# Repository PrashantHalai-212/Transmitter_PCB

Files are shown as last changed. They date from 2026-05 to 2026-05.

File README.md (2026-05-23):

# Transmitter_PCB

A Batman-inspired Batarang-shaped wireless transmitter board featuring an ATmega328P microcontroller, NRF24L01 module, and onboard CH340G USB programmer. Essentially an Arduino with integrated wireless capability and custom PCB design shaped like Batman's iconic throwing weapon.

## PCB Design

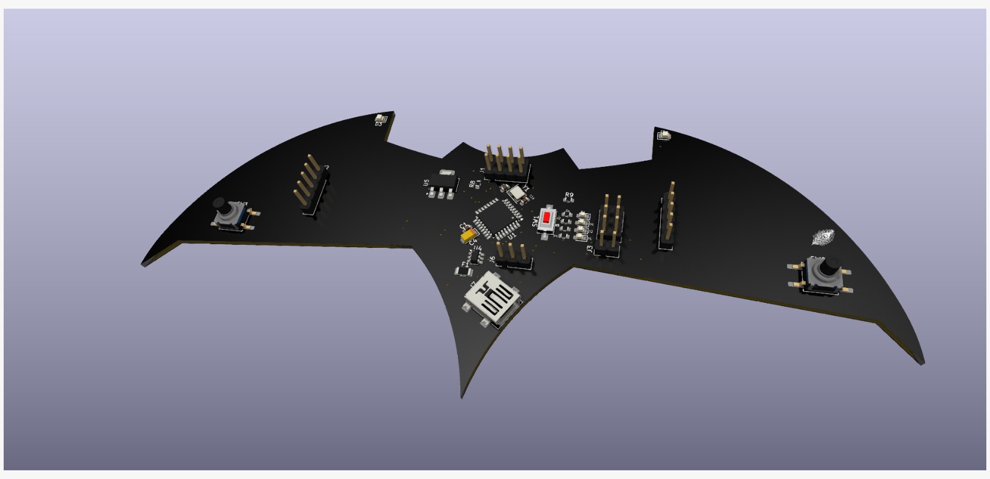
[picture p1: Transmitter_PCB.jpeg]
Batarang PCB Render


## Features

- **ATmega328P Microcontroller** - Same as Arduino
- **NRF24L01 Wireless Module** - 2.4GHz RF Communication
- **CH340G USB Programmer** - Direct programming without external programmer
- **Batarang Shape** - Batman-inspired custom PCB design
- **Full Arduino Compatibility** - Use standard Arduino sketches
- **All Supporting Components** - Crystal oscillator, capacitors, USB connector

## Files

- `Transmitter_PCB.kicad_sch` - Schematic design
- `Transmitter_PCB.kicad_pcb` - PCB layout
- `Transmitter_PCB.kicad_pro` - Project file

## Requirements

- KiCad 6.0 or later
- Arduino IDE (for programming)

## License

MIT

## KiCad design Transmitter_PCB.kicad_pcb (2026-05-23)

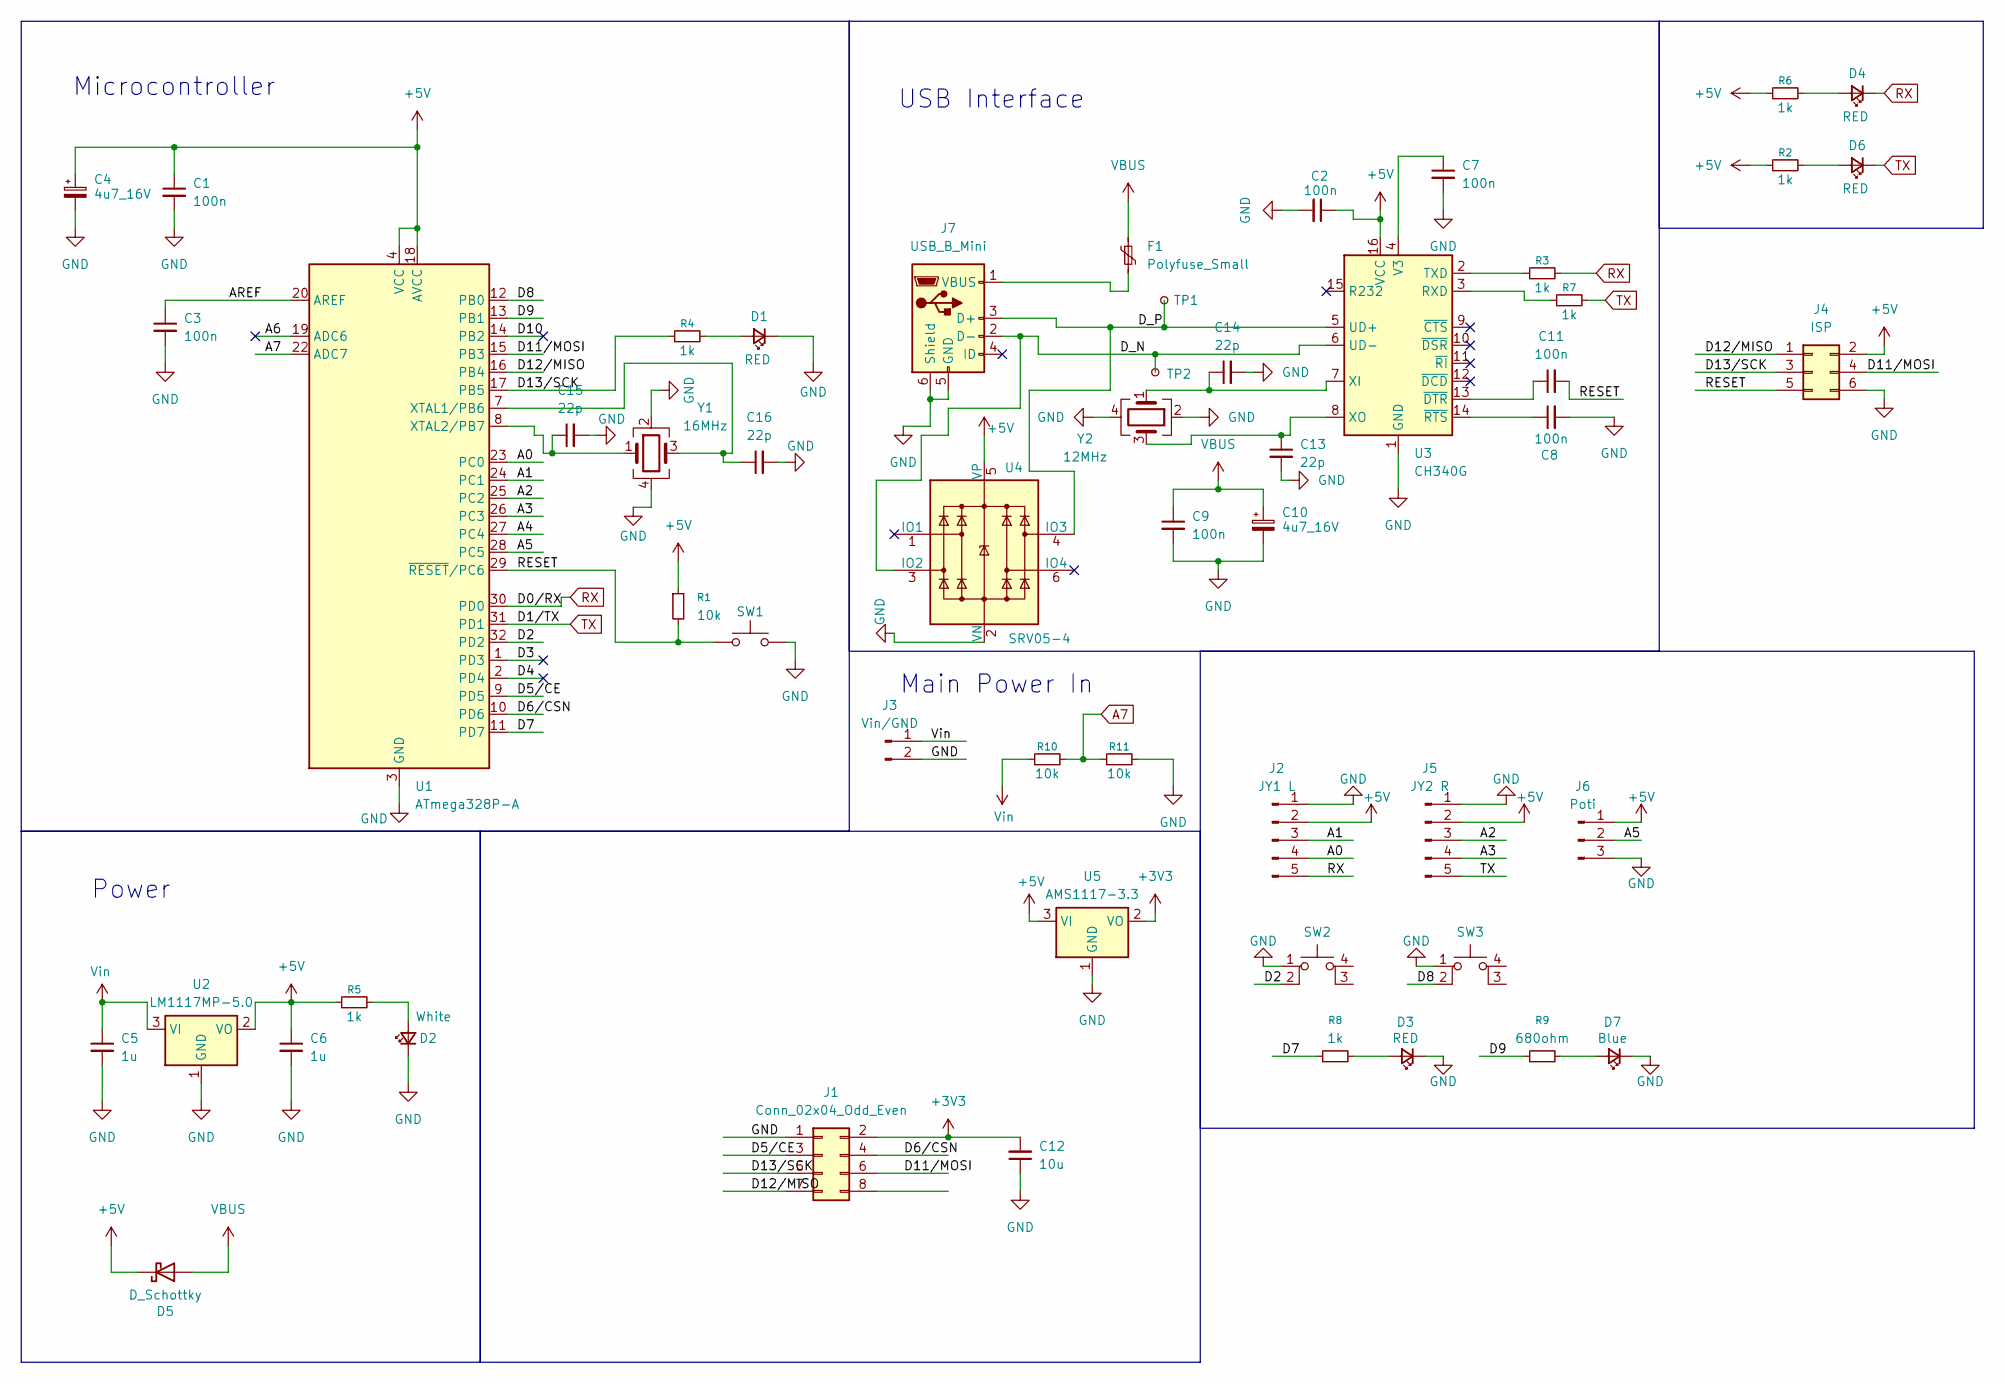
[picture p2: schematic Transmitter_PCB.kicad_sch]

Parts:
C1, C2, C3, C7, C8, C9, C11: 100n; C_0603_1608Metric
C4, C10: 4u7_16V; CP_EIA-3216-10_Kemet-I
C5, C6: 1u; C_0603_1608Metric
C12: 10u; C_0603_1608Metric
C13, C14, C15, C16: 22p; C_0603_1608Metric
D1, D4, D6: RED; LED_0603_1608Metric_Pad1.05x0.95mm_HandSolder
D2: White; LED_0603_1608Metric_Pad1.05x0.95mm_HandSolder
D3: RED; LED_0805_2012Metric
D5: D_Schottky; D_SOD-123
D7: Blue; LED_0805_2012Metric
F1: Polyfuse_Small; Fuse_1206_3216Metric
J1: Conn_02x04_Odd_Even; PinHeader_2x04_P2.54mm_Vertical
J2: JY1 L; PinHeader_1x05_P2.54mm_Vertical
J3: Vin/GND; PinHeader_1x02_P2.54mm_Vertical
J4: ISP; PinHeader_2x03_P2.54mm_Vertical
J5: JY2 R; PinHeader_1x05_P2.54mm_Vertical
J6: Poti; PinHeader_1x03_P2.54mm_Vertical
J7: USB_B_Mini; USB_Mini-B_Lumberg_2486_01_Horizontal
R1, R10, R11: 10k; R_0603_1608Metric
R2, R3, R4, R5, R6, R7, R8: 1k; R_0603_1608Metric
R9: 680ohm; R_0603_1608Metric
SW1: SW_Push; SW_SPST_CK_RS282G05A3
SW2, SW3: SW_Push_1P1T_NO_CK_KSC6xxG
TP1, TP2: TestPoint_Small; TestPoint_Pad_D1.0mm
U1: ATmega328P-A; TQFP-32_7x7mm_P0.8mm
U2: LM1117MP-5.0; SOT-223-3_TabPin2
U3: CH340G; SOIC-16_3.9x9.9mm_P1.27mm
U4: SRV05-4; SOT-23-6
U5: AMS1117-3.3; SOT-223-3_TabPin2
Y1: 16MHz; Crystal_SMD_3225-4Pin_3.2x2.5mm
Y2: 12MHz; Crystal_SMD_3225-4Pin_3.2x2.5mm

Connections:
+3V3: C12.2, J1.2, U5.2 (VO)
+5V: C1.1, C2.1, C4.1, C6.1, D5.1 (K), J2.2, J4.2, J5.2, J6.1, R1.1, R2.1, R5.1, R6.1, U1.4 (VCC), U1.6 (VCC), U1.18 (AVCC), U2.2 (VO), U3.16 (VCC), U4.5 (VP), U5.3 (VI)
/A0: J2.4, U1.23 (PC0)
/A1: J2.3, U1.24 (PC1)
/A2: J5.3, U1.25 (PC2)
/A3: J5.4, U1.26 (PC3)
/A4: U1.27 (PC4)
/A5: J6.2, U1.28 (PC5)
/A6: U1.19 (ADC6)
/AREF: C3.1, U1.20 (AREF)
/D2: SW2.2, U1.32 (PD2)
/D3: U1.1 (PD3)
/D4: U1.2 (PD4)
/D5/CE: J1.3, U1.9 (PD5)
/D6/CSN: J1.4, U1.10 (PD6)
/D7: R8.1, U1.11 (PD7)
/D8: SW3.2, U1.12 (PB0)
/D9: R9.1, U1.13 (PB1)
/D10: U1.14 (PB2)
/D11/MOSI: J1.6, J4.4, U1.15 (PB3)
/D12/MISO: J1.7, J4.1, U1.16 (PB4)
/D13/SCK: J1.5, J4.3, R4.1, U1.17 (PB5)
/D_N: J7.2 (D-), TP2.1, U3.6 (UD-), U4.3 (IO2)
/D_P: J7.3 (D+), TP1.1, U3.5 (UD+), U4.4 (IO3)
/RESET: C11.2, J4.5, R1.2, SW1.1, U1.29 (~RESET/PC6)
A7: R10.2, R11.1, U1.22 (ADC7)
GND: C1.2, C2.2, C3.2, C4.2, C5.2, C6.2, C7.2, C8.2, C9.2, C10.2, C12.1, C13.2, C14.2, C15.2, C16.2, D1.1 (K), D2.1 (K), D3.1 (K), D7.1 (K), J1.1, J2.1, J3.2, J4.6, J5.1, J6.3, J7.5 (GND), J7.6 (Shield), R11.2, SW1.2, SW2.1, SW3.1, U1.3 (GND), U1.5 (GND), U1.21 (GND), U2.1 (GND), U3.1 (GND), U4.2 (VN), U5.1 (GND), Y1.2, Y1.4, Y2.2, Y2.4
unnamed: D1.2 (A), R4.2
unnamed: D2.2 (A), R5.2
unnamed: D3.2 (A), R8.2
unnamed: D4.2 (A), R6.2
unnamed: D6.2 (A), R2.2
unnamed: D7.2 (A), R9.2
unnamed: F1.2, J7.1 (VBUS)
unnamed: C16.1, U1.7 (XTAL1/PB6), Y1.3
unnamed: C15.1, U1.8 (XTAL2/PB7), Y1.1
unnamed: R7.1, U3.3 (RXD)
unnamed: R3.1, U3.2 (TXD)
unnamed: C7.1, U3.4 (V3)
unnamed: C14.1, U3.7 (XI), Y2.1
unnamed: C13.1, U3.8 (XO), Y2.3
unnamed: C11.1, U3.13 (~DTR)
unnamed: C8.1, U3.14 (~RTS)
RX: D4.1 (K), J2.5, R3.2, U1.30 (PD0)
TX: D6.1 (K), J5.5, R7.2, U1.31 (PD1)
VBUS: C9.1, C10.1, D5.2 (A), F1.1
Vin: C5.1, J3.1, R10.1, U2.3 (VI)

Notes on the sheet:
Power
Main Power In
USB Interface
Microcontroller

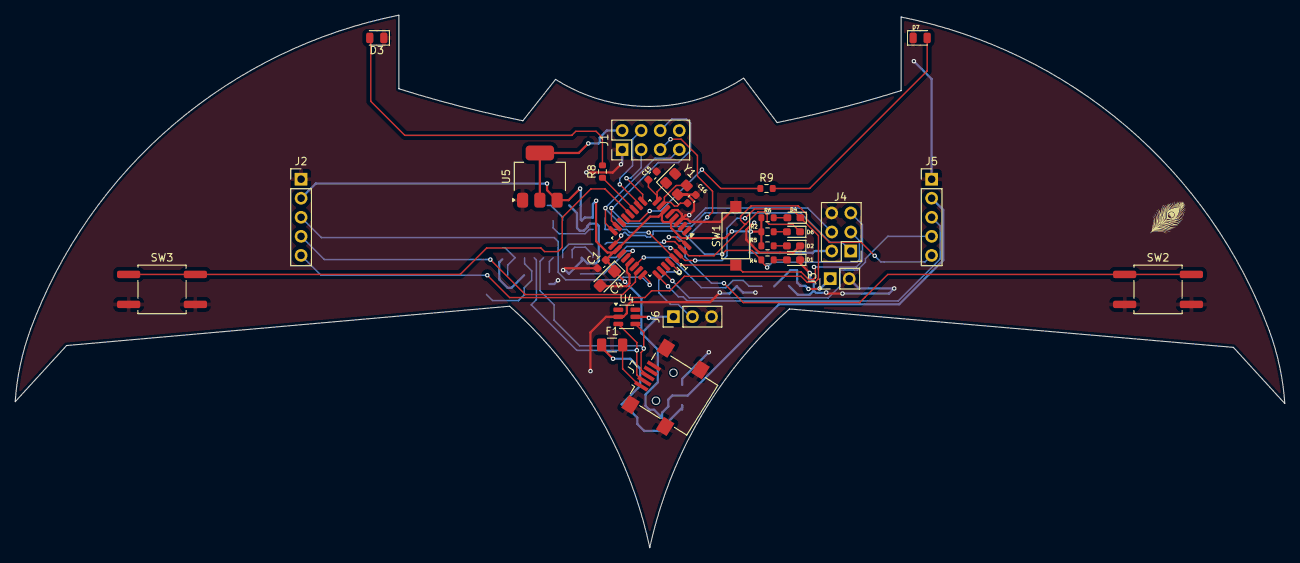
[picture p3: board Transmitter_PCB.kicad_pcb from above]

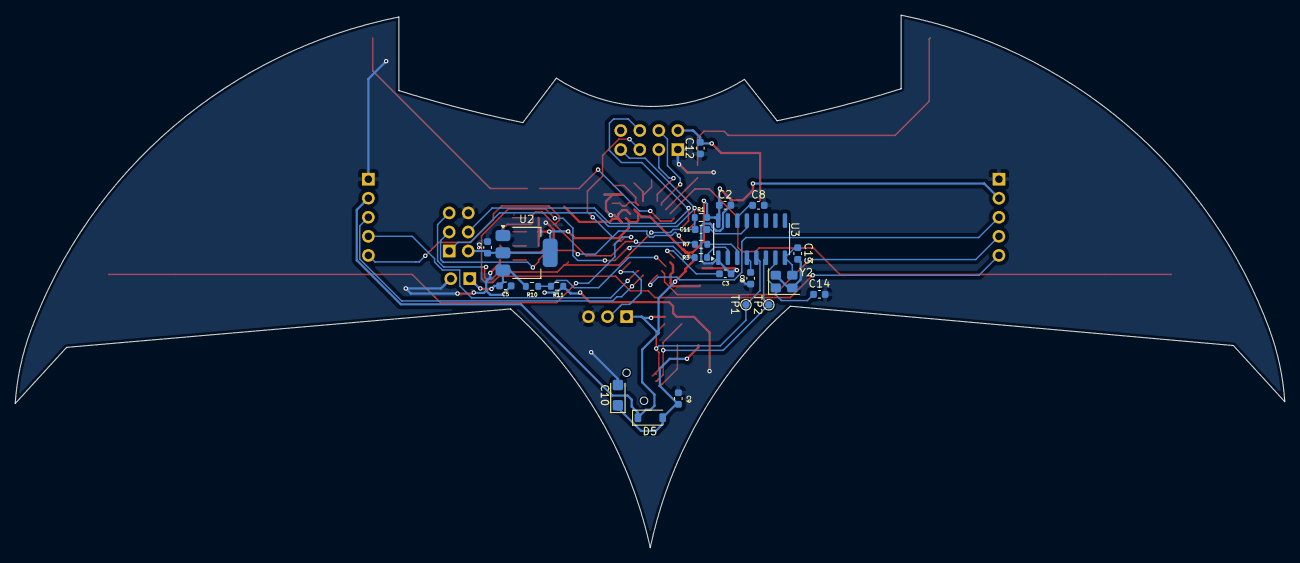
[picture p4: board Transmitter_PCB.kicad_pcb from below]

Board: 2 copper layers, 169.4 x 71.0 mm, 54 parts (23 on the bottom side), 42 nets.

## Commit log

2026-05-23 Initial commit: Add Batarang transmitter KiCAD project
    [Transmitter_PCB.kicad_pcb, Transmitter_PCB.kicad_sch]
2026-05-23 Add PCB render image
